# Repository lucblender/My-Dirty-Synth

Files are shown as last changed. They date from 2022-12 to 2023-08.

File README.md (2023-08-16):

# My-Dirty-Synth

Content:
 - Main Arduino code of the synth : [My-Dirty-Synth.ino](../master/My-Dirty-Synth.ino)
 - Front panel PCB in kicad 6.0 : hardware - [hardware - dirty synth folder](../master/hardware%20-%20dirty%20synth)

# Infos
This git contains all the files to realize your own "My-Dirty-Synth" made with the [Simple Synth kit](https://www.synthux.academy/simple) made by synthux academy. The synth is based on a [Daisy seed](https://www.electro-smith.com/daisy/daisy) by electro-smith and uses their Arduino library [DaisyDuino](https://github.com/electro-smith/DaisyDuino).

Each component of the synth (potentiometer, switch, jack) comes from the Simple Synth kit except what is linked to MIDI. For this, a custom PCB acting like a front panel has been made.

## Daisyduino warning

I'm using the daisysp wavefolder, it is not yet in the daisyduino library (tested the 19.04.2024 with daisyduino 1.6.3).

You need to get them in the daisysp library:
- [wavefolder.h](https://github.com/electro-smith/DaisySP/blob/master/Source/Effects/wavefolder.h)
- [wavefolder.cpp](https://github.com/electro-smith/DaisySP/blob/master/Source/Effects/wavefolder.cpp) 

You can put those two files in your daisyduino library path usually ```C:\Users\YourUserName\Documents\Arduino\libraries\DaisyDuino\src\utility\DaisySP\modules``` on Windows.

Then you'll need to do two modifications:

- on the _wavefolder.h_ file, replace line 6 ```
#include "Utility/dcblock.h"``` by ```#include "dcblock.h"```
- on the  _daisysp.h_ usually located ```C:\Users\YourUserName\Documents\Arduino\libraries\DaisyDuino\src\utility\DaisySP\daisysp.h``` you need to add ```#include "modules/wavefolder.h"``` on line 18. 

# Architecture

## Block diagram
Here is a block diagram of the synthesizer:
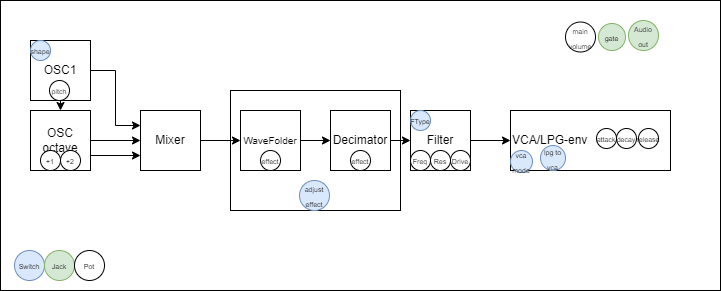
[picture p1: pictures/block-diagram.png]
Block diagram


The design starts with an oscillator whose shape can be chosen between sinus, triangle, sawtooth, and square. In addition to the main frequency, it is possible to have the 1st and 2nd octaves mixed with the main oscillator.

The signal is then sent to the effects:
- a wavefolder 
- a decimator

Both effects have a potentiometer to drive their strength.

A 3 positions switch helps to use those two effects combined:
- position 0: wavefolder only to maximum range
- position 1: wavefolder to maximum range and decimator reduced range
- position 2: wavefolder reduced range and decimator maximum range

When passing from one mode to the other, the range of value of the effect will slowly swipe to fit the selected range. This swipe last for ~2 secs.

The next module is the filter. You can change the filter resonance, cutoff frequency, and drive. With two switch you can change from
- no filter
- high pass filter
- low pass filter
- bandpass filter.

Finally, you can find the signal can pass through a VCA or lowpass gate with attack decay and release adjustable.
You can either activate the VCA/LPG with the VCA Mode switch and then select what kind of system you want your signal to pass through:
- VCA
- LPG
- VCA+LPG

## MIDI implementation

The MIDI listens by default to **channel 1**. It reacts to changes in note On, note Off, pitch bend, and control change. 
The control change affects the filter cutoff frequency.

- Note On/Off will change the pitch. Be sure to set the oscillator's main frequency potentiometer to its minimum to avoid interference with MIDI.
- Control changes will change the cutoff frequency of the filter. Be sure to set the cutoff frequency potentiometer to its minimum to avoid interference with MIDI.

A button hooked to D13 can be used to change the MIDI channel. When pressed, the new MIDI channel will be saved according to the oscillator type and filter type switches values in binary  + 1.

For example, if you want to get MIDI channel 7, you will need to set the switch to 6 in binary 0b0110 which corresponds to Triangle oscillator and low pass filter, and then press the MIDI Channel selection button.

## Gpios
| Bloc | Description | Components | Gpios | Daisy pin | Simple Patch | Simple Pin | Notes  |
|:---:|:---:|:---:|:---:|:---:|:---:|:---:|:---:|
| Oscillator | Main frequency | Pot | A11 | 35 | 6 | 43 | |
| Oscillator | Octave 1 | Pot | A10 | 32 | 8 | 40 | |
| Oscillator | Octave 2 | Pot | A9 | 31 | 13 | 39 | |
| Effects | Wavefolder factor | Pot | A8 | 30 | 22 | 38 | |
| Effects | Decimator factor | Pot | A7 | 29 | 33 | 37 | |
| Filter | Res frequency | Pot | A6 | 28 | 42 | 36 | |
| Filter | Filter drive | Pot | A5 | 27 | 44 | 35 | |
| Filter | Filter cutoff freq | Pot | A4 | 26 | 53 | 34 | |
| VCA/LPG | Attack | Pot | A3 | 25 | 67 | 33 | |
| VCA/LPG | Release | Pot | A2 | 24 | 69 | 32 | |
| VCA/LPG | Decay | Pot | A1 | 23 | 73 | 31 | |
| General | Main volume | Pot | A0 | 22 | 71 | 30 | |
| Oscillator | Oscillator type | Switch 2 pos | 6 | 7 | 5 | 7 | |
| Oscillator | Oscillator type | Switch 2 pos | 7 | 8 | 10 | 8 | |
| Effects | Effect mode selection | Switch 3 pos 1.1 | 8 | 9 | 28 | 9 | |
| Effects | Effect mode selection | Switch 3 pow 1.2 | 9 | 10 | 29 | 10 | |
| Filter | Filter type | Switch 2 pos | 10 | 11 | 50 | 11 | |
| Filter | Filter type | Switch 2 pos | 11 | 12 | 55 | 12 | |
| VCA/LPG | VCA Mode | Switch 2 pos | 12 | 13 | 61 | 13 | |
| General | Gate out signal | Jack | 5 | 6 | 66 | 6 | |
| VCA/LPG | VCA LPG selection | Switch 3 pos 2.1 | 4 | 5 | 78 | 5 | |
| VCA/LPG | VCA LPG selection | Switch 3 pos 2.2 | 3 | 4 | 79 | 4 | |
| MIDI | MIDI Channel selection button| Button | 13 | 14 | (16)\* | 14 | |
| MIDI | MIDI input | MIDI connector | 1 | 2 | | | UART |
| Output | AudioOut[0] | Mono Jack | AudioOut1 | 18 | 76 | 18 | |
| Output | AudioOut[1] | Mono Jack | AudioOut2 | 19 | | | Not used |

*The MIDI channel selection button can be put anywhere you want, accessible or not, depending on your usage. In my case, I put a discreet button on simple patch 16. I put it in this location, so it is not really visible and can be accessed through the front panel window, as shown in the following picture:

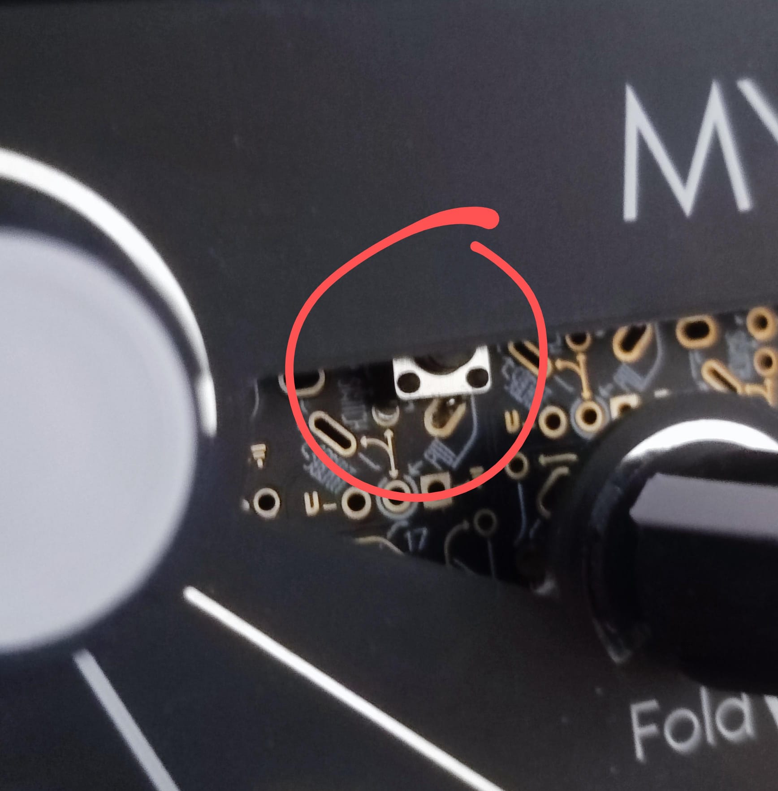
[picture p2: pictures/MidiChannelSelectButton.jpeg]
Midi channel selection button


# Pictures

## Front panel design
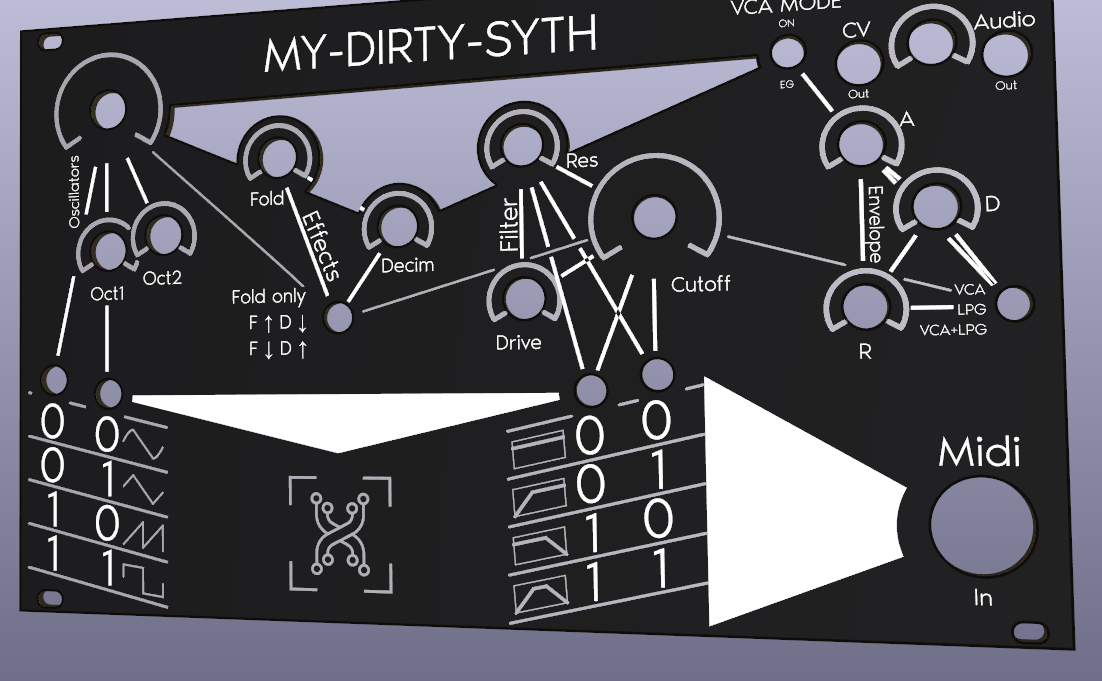
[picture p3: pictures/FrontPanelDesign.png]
Front panel desing


## Wiring

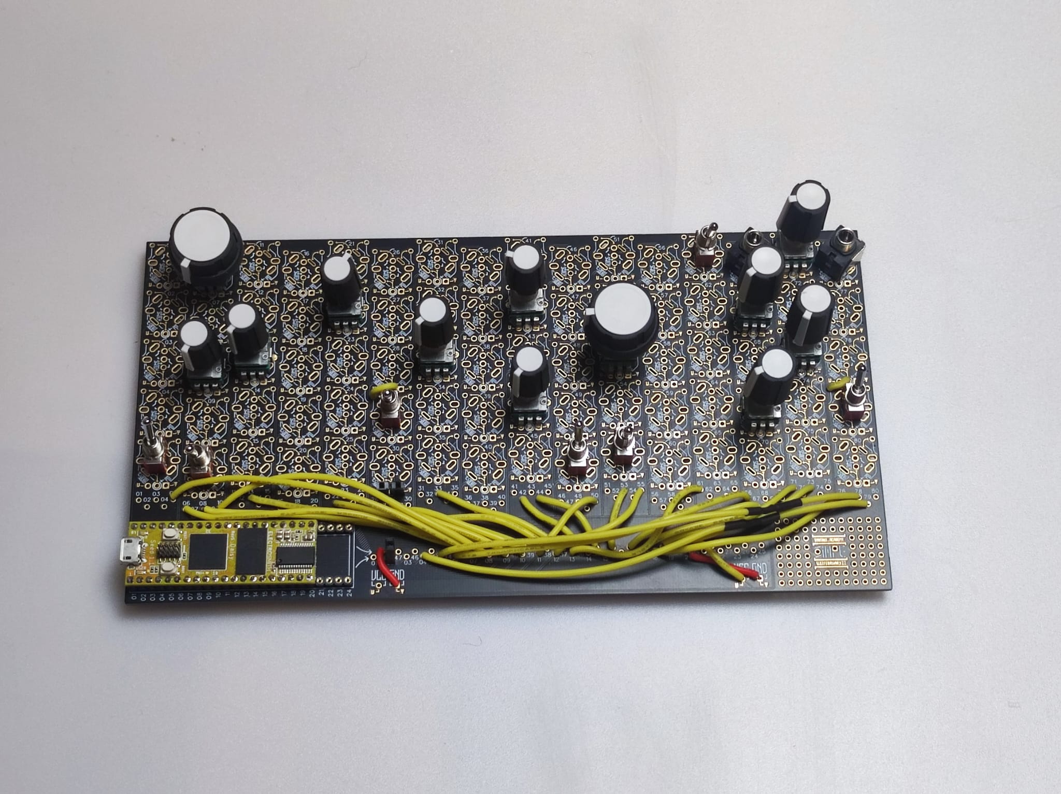
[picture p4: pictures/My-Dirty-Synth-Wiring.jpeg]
My-Dirty-Synth wiring


# Contribution

Thanks the synthux academy community for their support and to lemkipper for contributing and putting the documentation to the test while building My-Dirty-Synth.

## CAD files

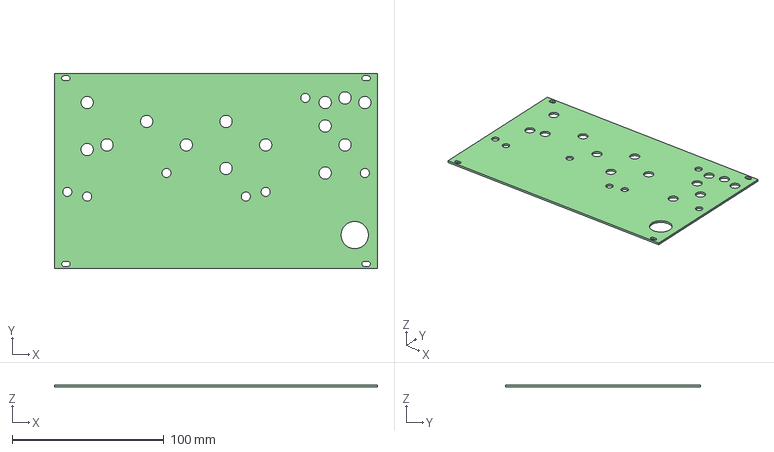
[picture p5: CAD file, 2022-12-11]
hardware - dirty synth/front-face-midi.step
213.0 x 128.5 x 1.60 mm

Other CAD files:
hardware - dirty synth/front-face-midi PCB.3mf

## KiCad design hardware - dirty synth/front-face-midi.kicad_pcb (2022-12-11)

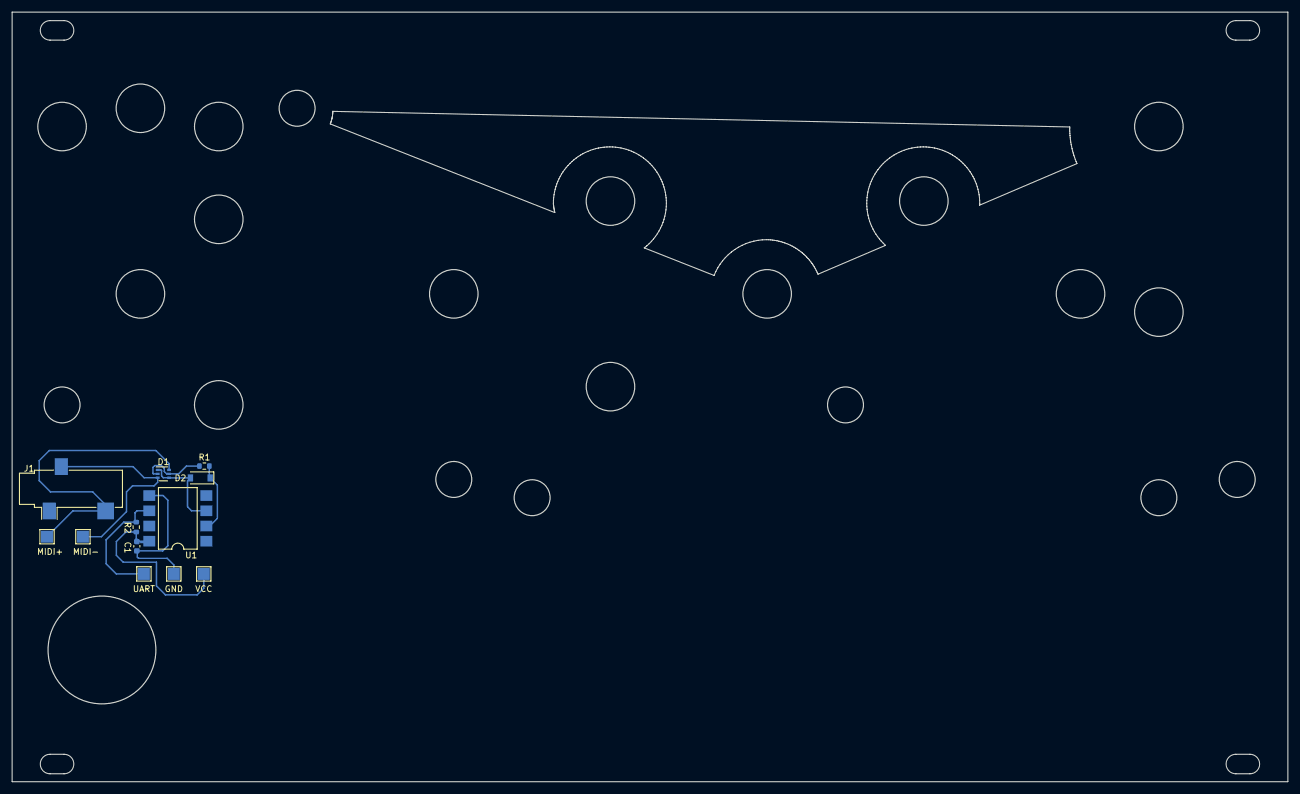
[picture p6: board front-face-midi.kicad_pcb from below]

Board: 2 copper layers, 213.0 x 128.5 mm, 12 parts (12 on the bottom side), 8 nets.

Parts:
C1: 100n; C_0603_1608Metric
D1: BAT54XY; SOT-363_SC-70-6
D2: 1N4148; D_SOD-123
J1: AudioJack3; Jack_3.5mm_CUI_SJ-3523-SMT_Horizontal
J2: UART; TestPoint_Pad_2.0x2.0mm
J3: GND; TestPoint_Pad_2.0x2.0mm
J4: VCC; TestPoint_Pad_2.0x2.0mm
J5: MIDI_DIN4; TestPoint_Pad_2.0x2.0mm
J6: MIDI_DIN5; TestPoint_Pad_2.0x2.0mm
R1: 220R; R_0603_1608Metric
R2: 10k; R_0603_1608Metric
U1: 6N137; SMDIP-8_W9.53mm

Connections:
+3V3: C1.1, J4.1, R2.2, U1.8 (VCC)
/uart: J2.1, R2.1, U1.6 (VO)
GND: C1.2, J3.1, U1.5 (GND)
unnamed: D1.1 (anode_1), D1.4 (anode4), D2.2 (A), U1.3 (C)
unnamed: D1.2 (cathode_2), D1.5 (cathode3), R1.2
unnamed: D1.3 (anode3/cathode4), J1.R, J5.1
unnamed: D1.6 (cathode1/anode2), J1.T, J6.1
unnamed: D2.1 (K), R1.1, U1.2 (A)

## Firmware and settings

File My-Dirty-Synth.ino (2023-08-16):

////////////////////////////////////////////////////////////////
///////////////////// VARIABLES & LIBRARIES ////////////////////

#include "DaisyDuino.h"
#include <MIDI.h>

using namespace daisysp;

HardwareSerial SerialMidi(1, 2);
MIDI_CREATE_INSTANCE(HardwareSerial, SerialMidi, myMidi);



////////////////////////////////////////////////////////////////
///////////////////// INPUT OUTPUT DEFINITION///////////////////

#define AN_MAIN_FREQ A11
#define AN_OCTAVE_1 A10
#define AN_OCTAVE_2 A9
#define AN_WAVEFOLD A8
#define AN_BITCRUSH A7
#define AN_F_RES A6
#define AN_F_DRIVE A5
#define AN_F_FREQ A4
#define AN_DYNC_ATT A3
#define AN_DYNC_REL A2
#define AN_DYNC_DEC A1
#define AN_MAIN_VOLUME A0

#define DI_I_OSC_TYPE_0 6
#define DI_I_OSC_TYPE_1 7
#define DI_I_CRUSH_FOLD_0 8
#define DI_I_CRUSH_FOLD_1 9
#define DI_I_FILTER_TYPE_0 10
#define DI_I_FILTER_TYPE_1 11
#define DI_I_VCA_MODE 12
#define DI_O_PULSE 5
#define DI_I_GATE_TYPE_0 4
#define DI_I_GATE_TYPE_1 3
#define DI_I_MIDI_CHANNEL_UPDATE 13

#define OSCILLATORS_FACTOR 1

float mainFreq;
float mainFreqUp;
float mainFreqDown;
float midiFreq = -1;
float mainFreqOLD = -1;
float octave1Factor;
float octave1FactorOLD = -1;
float octave2Factor;
float octave2FactorOLD = -1;
float wavefolderFactor;
float wavefolderFactorOLD = -1;
float bitcrushFactor;
float bitcrushFactorOLD = -1;
float filterRes;
float filterResOLD = -1;
float filterDrive;
float filterDriveOLD = -1;
float filterFreq;
float filterFreqOLD = -1;
float filterMidiFreq = -1;
float filterMidiFreqOLD = -1;
float dyncAttack;
float dyncAttackOLD = -1;
float dyncDecay;
float dyncDecayOLD = -1;
float dyncRelease;
float dyncReleaseOLD = -1;
float mainVolume;
float mainVolumeOLD = -1;

float effectFactorWaveFolderSetpoint = 1.0f;
float effectFactorBitCrusher = 1.0f;
float effectFactorWaveFolder = 1.0f;
float effectFactorBitCrusherSetpoint = 1.0f;

uint8_t oscType0;
uint8_t oscType0OLD = 10;
uint8_t oscType1;
uint8_t oscType1OLD = 10;
uint8_t crushFold0;
uint8_t crushFold0OLD = 10;
uint8_t crushFold1;
uint8_t crushFold1OLD = 10;
uint8_t crushFoldType;
uint8_t filterType0;
uint8_t filterType0OLD = 10;
uint8_t filterType1;
uint8_t filterType;
uint8_t filterType1OLD = 10;
uint8_t vcaMode;
uint8_t vcaModeOLD = 10;
uint8_t gateType0;
uint8_t gateType0OLD = 10;
uint8_t gateType1;
uint8_t gateType1OLD = 10;
uint8_t gateType;

bool gate = false;

int titi = 0;

uint8_t listeningMidiChannel = 1;

#define TRIGGER_DIFF 0.01

////////////////////////////////////////////////////////////////
///////////////////// MODULES //////////////////////////////////


static Oscillator osc;
static Oscillator oscOctaveOne;
static Oscillator oscOctaveTwo;
Wavefolder wavefolder;
Decimator bitcrusher;
Svf funkyFilter;
MoogLadder lowPassGate;
Adsr adsr;
float frequency = 440;
float sample_rate;

float filterFrequency;


////////////////////////////////////////////////////////////////
///////////////////// START SYNTH SETUP ////////////////////////

void midiBtnReleased() {
  if (digitalRead(DI_I_MIDI_CHANNEL_UPDATE) == 1) {

    uint8_t midi_channel_0 = digitalRead(DI_I_FILTER_TYPE_1);
    uint8_t midi_channel_1 = digitalRead(DI_I_FILTER_TYPE_0) << 1;
    uint8_t midi_channel_2 = digitalRead(DI_I_OSC_TYPE_1) << 2;
    uint8_t midi_channel_3 = digitalRead(DI_I_OSC_TYPE_0) << 3;
    listeningMidiChannel = midi_channel_3 + midi_channel_2 + midi_channel_1 + midi_channel_0 + 1;
  }
}

void setup() {
  Serial.begin(15200);

  myMidi.setHandleNoteOn(handleNoteOn);
  myMidi.setHandleNoteOff(handleNoteOff);
  myMidi.setHandlePitchBend(handlePitchBend);
  myMidi.setHandleControlChange(handleControlChange);
  myMidi.begin(MIDI_CHANNEL_OMNI);

  //Setupt input outputs
  pinMode(DI_I_OSC_TYPE_0, INPUT_PULLUP);
  pinMode(DI_I_OSC_TYPE_1, INPUT_PULLUP);
  pinMode(DI_I_CRUSH_FOLD_0, INPUT_PULLUP);
  pinMode(DI_I_CRUSH_FOLD_1, INPUT_PULLUP);
  pinMode(DI_I_FILTER_TYPE_0, INPUT_PULLUP);
  pinMode(DI_I_FILTER_TYPE_1, INPUT_PULLUP);
  pinMode(DI_I_VCA_MODE, INPUT_PULLUP);
  pinMode(DI_O_PULSE, OUTPUT);
  pinMode(DI_I_GATE_TYPE_0, INPUT_PULLUP);
  pinMode(DI_I_GATE_TYPE_1, INPUT_PULLUP);
  pinMode(DI_I_MIDI_CHANNEL_UPDATE, INPUT_PULLUP);
  attachInterrupt(digitalPinToInterrupt(DI_I_MIDI_CHANNEL_UPDATE), midiBtnReleased, RISING);

  // DAISY SETUP
  DAISY.init(DAISY_SEED, AUDIO_SR_48K);

  wavefolder.Init();
  wavefolder.SetGain(1);
  wavefolder.SetOffset(0);

  sample_rate = DAISY.get_samplerate();

  bitcrusher.Init();
  bitcrusher.SetDownsampleFactor(0.4f);
  funkyFilter.Init(sample_rate);

  lowPassGate.Init(sample_rate);
  lowPassGate.SetFreq(sample_rate);

  // OSCILLATOR SETUP
  osc.Init(sample_rate);
  oscOctaveOne.Init(sample_rate);
  oscOctaveTwo.Init(sample_rate);
  setGlobalFrequency(440);
  osc.SetAmp(OSCILLATORS_FACTOR);
  oscOctaveOne.SetAmp(0);
  oscOctaveTwo.SetAmp(0);

  osc.SetWaveform(osc.WAVE_SIN);
  oscOctaveOne.SetWaveform(osc.WAVE_SIN);
  oscOctaveTwo.SetWaveform(osc.WAVE_SIN);

  adsr.Init(sample_rate);

  adsr.SetSustainLevel(.3);


  // DAISY SETUP
  DAISY.begin(ProcessAudio);
}


///////////////////// END SYNTH SETUP //////////////////////////
////////////////////////////////////////////////////////////////


////////////////////////////////////////////////////////////////
///////////////////// PROCESSING AUDIO SAMPLES (LOOP) //////////


void ProcessAudio(float **in, float **out, size_t size) {

  float adsrGain;
  float afterAdsr;
  for (size_t i = 0; i < size; i++) {
    float sample = osc.Process();

    //if octave factor == 0, don't even compute the oscillator
    float sampleOctaveOne = (octave1Factor < 0.01) ? 0 : oscOctaveOne.Process();
    float sampleOctaveTwo = (octave2Factor < 0.01) ? 0 : oscOctaveTwo.Process();

    float addedOscillators = sample + sampleOctaveOne + sampleOctaveTwo;

    float withEffects;

    float withFilter;

    if (bitcrushFactor > 0.02)
      withEffects = bitcrusher.Process(((wavefolderFactor < 0.01) ? addedOscillators : wavefolder.Process(addedOscillators)));
    else
      withEffects = ((wavefolderFactor < 0.01) ? addedOscillators : wavefolder.Process(addedOscillators));


    switch (filterType) {
      case 0:
        withFilter = withEffects;
        break;
      case 1:
        funkyFilter.Process(withEffects);
        withFilter = funkyFilter.High();
        break;
      case 2:
        funkyFilter.Process(withEffects);
        withFilter = funkyFilter.Low();
        break;
      case 3:
        funkyFilter.Process(withEffects);
        withFilter = funkyFilter.Band();
        break;
    }


    if (vcaMode == 0) {
      adsrGain = 1.0;
      afterAdsr = withFilter;
    } else {
      switch (gateType) {
        //simple adsr
        case 1:
          adsrGain = adsr.Process(gate);
          afterAdsr = withFilter * adsrGain;
          break;
        //simple low pass gate
        case 3:
          adsrGain = adsr.Process(gate);
          lowPassGate.SetFreq((sample_rate / 2) * (adsrGain * adsrGain));
          afterAdsr = lowPassGate.Process(withFilter);
          break;
        //adsr + low pass gate
        case 2:
          adsrGain = adsr.Process(gate);
          lowPassGate.SetFreq((sample_rate / 2) * (adsrGain * adsrGain));
          float lpgOutput = lowPassGate.Process(withFilter);
          afterAdsr = lpgOutput * ((adsrGain * 3 / 4) + 0.25);
          break;
      }
    }




    float finalOutput = afterAdsr * mainVolume;

    out[0][i] = finalOutput;  //Filter.High();
    out[1][i] = finalOutput;  //funkyFilter.High();
  }
}


void setGlobalFrequency(float localFrequency) {
  frequency = localFrequency;
  osc.SetFreq(frequency);
  oscOctaveOne.SetFreq(frequency / 2);
  oscOctaveTwo.SetFreq(frequency / 4);
}

////////////////////////////////////////////////////////////////
///////////////////// START CONTROLS LOOP //////////////////////


void loop() {


  myMidi.read();
  // put your main code here, to run repeatedly:
  int freqNote = simpleAnalogReadAndMap(AN_MAIN_FREQ, -57, 70);
  mainFreq = semitone_to_hertz(freqNote);
  octave1Factor = simpleAnalogRead(AN_OCTAVE_1);
  octave2Factor = simpleAnalogRead(AN_OCTAVE_2);
  wavefolderFactor = simpleAnalogRead(AN_WAVEFOLD);
  bitcrushFactor = simpleAnalogRead(AN_BITCRUSH);
  filterRes = simpleAnalogRead(AN_F_RES);
  filterDrive = simpleAnalogRead(AN_F_DRIVE);
  filterFreq = simpleAnalogRead(AN_F_FREQ);
  dyncAttack = simpleAnalogRead(AN_DYNC_ATT);
  dyncDecay = simpleAnalogRead(AN_DYNC_DEC);
  dyncRelease = simpleAnalogRead(AN_DYNC_REL);
  mainVolume = simpleAnalogRead(AN_MAIN_VOLUME);

  oscType0 = digitalRead(DI_I_OSC_TYPE_0);
  oscType1 = digitalRead(DI_I_OSC_TYPE_1);
  crushFold0 = digitalRead(DI_I_CRUSH_FOLD_0);
  crushFold1 = digitalRead(DI_I_CRUSH_FOLD_1);
  filterType0 = digitalRead(DI_I_FILTER_TYPE_0);
  filterType1 = digitalRead(DI_I_FILTER_TYPE_1);
  vcaMode = digitalRead(DI_I_VCA_MODE);
  gateType0 = digitalRead(DI_I_GATE_TYPE_0);
  gateType1 = digitalRead(DI_I_GATE_TYPE_1);


#ifdef DEBUG_PRINT_SWITCH
  Serial.print("oscType0 ");
  Serial.print(oscType0);
  Serial.print(", oscType1 ");
  Serial.print(oscType1);
  Serial.print(", crushFold0 ");
  Serial.print(crushFold0);
  Serial.print(", crushFold1 ");
  Serial.print(crushFold1);
  Serial.print(", filterType0 ");
  Serial.print(filterType0);
  Serial.print(", filterType1 ");
  Serial.print(filterType1);
  Serial.print(", vcaMode ");
  Serial.println(vcaMode);
#endif

#ifdef DEBUG_PRINT_POTENTIOMETERS
  Serial.print("mainFreq ");
  Serial.print(mainFreq);
  Serial.print(" ,octave1Factor ");
  Serial.print(octave1Factor);
  Serial.print(" ,octave2Factor ");
  Serial.print(octave2Factor);
  Serial.print(" ,wavefolderFactor ");
  Serial.print(wavefolderFactor);
  Serial.print(" ,bitcrushFactor ");
  Serial.print(bitcrushFactor);
  Serial.print(" ,filterRes ");
  Serial.print(filterRes);
  Serial.print(" ,filterDrive ");
  Serial.print(filterDrive);
  Serial.print(" ,filterFreq ");
  Serial.print(filterFreq);
  Serial.print(" ,dyncAttack ");
  Serial.print(dyncAttack);
  Serial.print(" ,dyncDecay ");
  Serial.print(dyncDecay);
  Serial.print(" ,dyncRelease ");
  Serial.print(dyncRelease);
  Serial.print(" ,AN_MAIN_VOLUME ");
  Serial.println(mainVolume);
#endif
  if (mainFreq != mainFreqOLD) {

    if (mainFreq < 10 && midiFreq != -1)  //if frequency is at its lowest and midi fequency has been changed, don't update frequency*
    {
      //do nothing
    } else {
      setGlobalFrequency(mainFreq);
    }
    mainFreqOLD = mainFreq;
  }
  if (abs(octave1Factor - octave1FactorOLD) > TRIGGER_DIFF) {
    oscOctaveOne.SetAmp(octave1Factor * OSCILLATORS_FACTOR);

    octave1FactorOLD = octave1Factor;
  }
  if (abs(octave2Factor - octave2FactorOLD) > TRIGGER_DIFF) {
    oscOctaveTwo.SetAmp(octave2Factor * OSCILLATORS_FACTOR);

    octave2FactorOLD = octave2Factor;
  }
  if ((abs(wavefolderFactor - wavefolderFactorOLD) > TRIGGER_DIFF) || (effectFactorWaveFolderSetpoint != effectFactorWaveFolder)) {
    wavefolder.SetGain(5.0 * (wavefolderFactor * effectFactorWaveFolder) + 1.0);
    wavefolder.SetOffset(1.3 * (wavefolderFactor * effectFactorWaveFolder));

    wavefolderFactorOLD = wavefolderFactor;
  }
  if ((abs(bitcrushFactor - bitcrushFactorOLD) > TRIGGER_DIFF) || (effectFactorBitCrusher != effectFactorBitCrusherSetpoint)) {
    int convertedBitFactor = (bitcrushFactor)*9.5 + 0;
    convertedBitFactor = convertedBitFactor;

    bitcrusher.SetBitsToCrush(convertedBitFactor);                       //convertedBitFactor);
    float downsampleFactor = (bitcrushFactor * effectFactorBitCrusher);  //+ 0.5f;
    bitcrusher.SetDownsampleFactor(downsampleFactor);

    //bitcrusher.SetDownsampleFactor((sample_rate) * (1.1 - bitcrushFactor));
    bitcrushFactorOLD = bitcrushFactor;
  }
  if (abs(filterRes - filterResOLD) > TRIGGER_DIFF) {
    float res = 0.3 + (filterRes * 0.69);
    funkyFilter.SetRes(res);

    filterResOLD = filterRes;
  }
  if (abs(filterDrive - filterDriveOLD) > TRIGGER_DIFF) {
    float drive = filterDrive * 0.7;
    funkyFilter.SetDrive(drive);

    filterDriveOLD = filterDrive;
  }

  if (filterFreq != filterFreqOLD) {
    if (filterMidiFreq == -1) {
      // if midi mod freq never changed
      float cutoffFreq = (filterFreq) * (sample_rate / 4);
      funkyFilter.SetFreq(cutoffFreq);
    } else {
      // if midi mod freq never changed, need bigger change of filterFreq to update
      if (abs(filterFreq - filterFreqOLD) > 0.008) {
        filterMidiFreq = -1;
        float cutoffFreq = (filterFreq) * (sample_rate / 4);
        funkyFilter.SetFreq(cutoffFreq);
      }
    }
  }

  filterFreqOLD = filterFreq;

  if (abs(filterMidiFreq - filterMidiFreqOLD) > TRIGGER_DIFF) {
    float cutoffFreq = (filterMidiFreq) * (sample_rate / 4);
    funkyFilter.SetFreq(cutoffFreq);

    filterMidiFreqOLD = filterMidiFreq;
  }

  if (abs(dyncAttack - dyncAttackOLD) > TRIGGER_DIFF) {
    adsr.SetAttackTime(dyncAttack);

    dyncAttackOLD = dyncAttack;
  }
  if (abs(dyncDecay - dyncDecayOLD) > TRIGGER_DIFF) {
    adsr.SetDecayTime(dyncDecay);

    dyncDecayOLD = dyncDecay;
  }
  if (abs(dyncRelease - dyncReleaseOLD) > TRIGGER_DIFF) {
    adsr.SetReleaseTime(dyncRelease);

    dyncReleaseOLD = dyncRelease;
  }
  if (mainVolume != mainVolumeOLD) {
    mainVolumeOLD = mainVolume;
  }

  if (oscType0 != oscType0OLD || oscType1 != oscType1OLD) {
    int type = oscType0 + oscType1 * 2;

    switch (type) {
      case 0:
        osc.SetWaveform(osc.WAVE_SIN);
        oscOctaveOne.SetWaveform(osc.WAVE_SIN);
        oscOctaveTwo.SetWaveform(osc.WAVE_SIN);
        break;
      case 1:
        osc.SetWaveform(osc.WAVE_POLYBLEP_TRI);
        oscOctaveOne.SetWaveform(osc.WAVE_POLYBLEP_TRI);
        oscOctaveTwo.SetWaveform(osc.WAVE_POLYBLEP_TRI);
        break;
      case 2:
        osc.SetWaveform(osc.WAVE_POLYBLEP_SAW);
        oscOctaveOne.SetWaveform(osc.WAVE_POLYBLEP_SAW);
        oscOctaveTwo.SetWaveform(osc.WAVE_POLYBLEP_SAW);
        break;
      case 3:
        osc.SetWaveform(osc.WAVE_POLYBLEP_SQUARE);
        oscOctaveOne.SetWaveform(osc.WAVE_POLYBLEP_SQUARE);
        oscOctaveTwo.SetWaveform(osc.WAVE_POLYBLEP_SQUARE);
        break;
    }

    oscType0OLD = oscType0;
    oscType1OLD = oscType1;
  }

  if (crushFold0 != crushFold0OLD || crushFold1 != crushFold1OLD) {
    crushFoldType = crushFold0 + crushFold1 * 2;
    crushFold0OLD = crushFold0;
    crushFold1OLD = crushFold1;

    switch (crushFoldType) {
      case 1:  //Fold only
        effectFactorWaveFolderSetpoint = 1.0f;
        effectFactorBitCrusherSetpoint = 0.0f;
        break;
      case 3:  //F up D down
        effectFactorWaveFolderSetpoint = 1.0f;
        effectFactorBitCrusherSetpoint = 0.5f;
        break;
      case 2:  //F down D up
        effectFactorWaveFolderSetpoint = 0.2f;
        effectFactorBitCrusherSetpoint = 1.0f;
        break;
    }
  }
  if (filterType0 != filterType0OLD || filterType1 != filterType1OLD) {
    filterType = filterType0 + filterType1 * 2;

    filterType0OLD = filterType0;
    filterType1OLD = filterType1;
  }
  if (vcaMode != vcaModeOLD) {

    vcaModeOLD = vcaMode;
  }
  if (gateType0 != gateType0OLD || gateType1 != gateType1OLD) {
    gateType = gateType0 + gateType1 * 2;

    gateType0OLD = gateType0;
    gateType1OLD = gateType1;
  }

  if (effectFactorWaveFolderSetpoint != effectFactorWaveFolder) {
    if (effectFactorWaveFolderSetpoint > effectFactorWaveFolder) {
      effectFactorWaveFolder += 0.001;
    } else {
      effectFactorWaveFolder -= 0.001;
    }
    if (abs(effectFactorWaveFolderSetpoint - effectFactorWaveFolder) < 0.001) {
      effectFactorWaveFolder = effectFactorWaveFolderSetpoint;
    }
  }

  if (effectFactorBitCrusher != effectFactorBitCrusherSetpoint) {
    if (effectFactorBitCrusherSetpoint > effectFactorBitCrusher) {
      effectFactorBitCrusher += 0.001;
    } else {
      effectFactorBitCrusher -= 0.001;
    }
    if (abs(effectFactorBitCrusherSetpoint - effectFactorBitCrusher) < 0.001) {
      effectFactorBitCrusher = effectFactorBitCrusherSetpoint;
    }
  }
}

void handleNoteOn(byte inChannel, byte inNote, byte inVelocity) {
  if (listeningMidiChannel == inChannel) {
    if (inVelocity == 0) {
      handleNoteOff(inChannel, inNote, inVelocity);
    } else {
      midiFreq = semitone_to_hertz(inNote - 57);

      mainFreqUp = semitone_to_hertz(inNote - 57 + 1);
      mainFreqDown = semitone_to_hertz(inNote - 57 - 1);

      setGlobalFrequency(midiFreq);
      gate = true;
      digitalWrite(DI_O_PULSE, HIGH);
    }
  }
}

void handleNoteOff(byte inChannel, byte inNote, byte inVelocity) {

  if (listeningMidiChannel == inChannel) {
    Serial.println("handleNoteOff");
    gate = false;
    digitalWrite(DI_O_PULSE, LOW);
  }
}

void handlePitchBend(unsigned char inChannel, int data) {

  if (listeningMidiChannel == inChannel) {
    //data goest from -8192 to +8192
    if (data == 0) {
      setGlobalFrequency(midiFreq);
    } else if (data > 0) {
      float bendedFreq = (((mainFreqUp - midiFreq) / 8192.0f) * data);
      setGlobalFrequency(midiFreq + bendedFreq);
    } else if (data < 0) {
      float bendedFreq = (((midiFreq - mainFreqDown) / 8192.0f) * -data);
      setGlobalFrequency(midiFreq - bendedFreq);
    }
  }
}

void handleControlChange(unsigned char inChannel, unsigned char data1, unsigned char data2) {

  if (listeningMidiChannel == inChannel) {
    if (data1 == 1) {
      //data2 goes from 0 to 127
      filterMidiFreq = data2 / 127.0f;
    }
  }
}

float semitone_to_hertz(int8_t note_number) {
  return 220 * pow(2, ((float)note_number - 0) / 12);
}

float simpleAnalogRead(uint32_t pin) {
  return (1023.0 - (float)analogRead(pin)) / 1023.0;
}

// Reads a simple pot and maps it to a value bewtween to integer values
float simpleAnalogReadAndMap(uint32_t pin, long min, long max) {
  return map(1023 - analogRead(pin), 0, 1023, min, max);
}

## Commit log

2022-10-26 make it react to midi control change and pitch bend
2022-11-20 Better wavefold and bitcrush and inverted lowpass and highpass
    [My-Dirty-Synth.ino]
2022-12-11 added pcb files
    [front-face-midi PCB.3mf, front-face-midi.kicad_pcb, front-face-midi.kicad_sch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]
2022-12-18 Updated readme and added wiring picture
2023-04-19 better lpg, readme with wavefolder information
    better lpg with moogladder filter by daisysp, updated readme for wavefolder integration
2023-05-06 Update README.md wiring table
2023-08-16 add default midi channel (1) and possibility to set midi channel
    Can set midi channel if you wire a button on D13. The midi channel will then be equal to the binary code + 1 of the waveform + filter switches
